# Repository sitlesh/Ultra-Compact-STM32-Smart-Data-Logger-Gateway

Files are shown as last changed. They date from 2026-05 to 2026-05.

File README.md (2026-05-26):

# Custom Embedded Controller Board with Micro SD Storage

A professionally designed, compact **2-layer printed circuit board (PCB)** developed using **KiCad 8.0**. This hardware platform is engineered for standalone embedded applications requiring localized data logging, high-precision timing, and robust power delivery.

---

## 📸 Hardware Showcase

### 🏷️ 3D Render Preview
Ultra-Compact STM32 Smart Data Logger Gateway

### 🗺️ Board Layout (Top & Bottom View)
| Top Copper Layer (F.Cu) | Bottom Copper Layer (B.Cu) |
| :---: | :---: |
| Screenshot (32) | Screenshot (33) |

---

## 🚀 Key Hardware Features

* **Micro SD Card Slot (J4):** Wired via high-speed SPI interface. Features localized decoupling, direct short-return paths to ground, and integrated mechanical shield grounding (`SH GND`) to suppress ESD and EMI.
* **Dual-Clock Architecture:** * **High-Speed Crystal (Y1 - 8MHz):** Provides a stable external clock source for the primary microcontroller core, stabilized by 20pF loading capacitors.
  * **Low-Speed RTC Crystal (Y2 - 32.768kHz):** Dedicated ultra-low-power crystal with 10pF loading capacitors for precise time-stamping.
* **Power Management:** Heavy-duty 2-position screw terminal (`J1`) for power input, protected by a robust on-board Schottky/Rectifier Diode (`D1`) for reverse polarity protection.
* **Signal Integrity:** Utilizes duplicated, stitched copper zones (`GND`) across both layers to maximize thermal dissipation, lower loop inductance, and suppress high-frequency noise.

---

## 📁 Repository Directory & File Descriptions

This repository contains all the native design assets and manufacturing files required to replicate or modify this project.

### 🛠️ Source Design Files (KiCad 8.0)
* **[`Ultra-Compact STM32 Smart Data Logger & Gateway.kicad_pro`](./Ultra-Compact%20STM32%20Smart%20Data%20Logger%20%26%20Gateway.kicad_pro)** : The master KiCad project file that links the schematic and PCB layout configurations together.
* **[`Ultra-Compact STM32 Smart Data Logger & Gateway.kicad_sch`](./Ultra-Compact%20STM32%20Smart%20Data%20Logger%20%26%20Gateway.kicad_sch)** : The complete schematic capture. Contains the logical circuit connections, component symbols, and electrical nets.
* **[`Ultra-Compact STM32 Smart Data Logger & Gateway.kicad_pcb`](./Ultra-Compact%20STM32%20Smart%20Data%20Logger%20%26%20Gateway.kicad_pcb)** : The physical 2-layer board layout, trace routing, component footprints, and copper ground planes.
* **[`gitignore.txt`](./gitignore.txt)** : Configured to exclude local KiCad auto-saves and temporary backup files to keep the repository clean.

### 📦 Manufacturing Files
* **[`Download Pre-packaged Gerbers ZIP (Gerbers.zip)`](./Gerbers.zip)** : Contains the combined ZIP archive. Click this link and hit the **Download** button on the next page to get all production-ready Gerber and Drill files for direct manufacturing.

---

## ⚙️ Fabrication Specifications

| Parameter | Specification |
| :--- | :--- |
| **Material Type** | FR-4 Standard |
| **Layer Count** | 2 Layers |
| **Board Thickness** | 1.6 mm |
| **Copper Weight** | 1 oz (35μm) outer layers |
| **Surface Finish** | HASL (with lead) or ENIG |
| **Solder Mask** | User Preference (Green/Blue/Black) |
| **Silkscreen** | White (High contrast) |

---

## 📝 License
This hardware design is open-source. Feel free to clone, modify, and build upon it for your own custom applications.

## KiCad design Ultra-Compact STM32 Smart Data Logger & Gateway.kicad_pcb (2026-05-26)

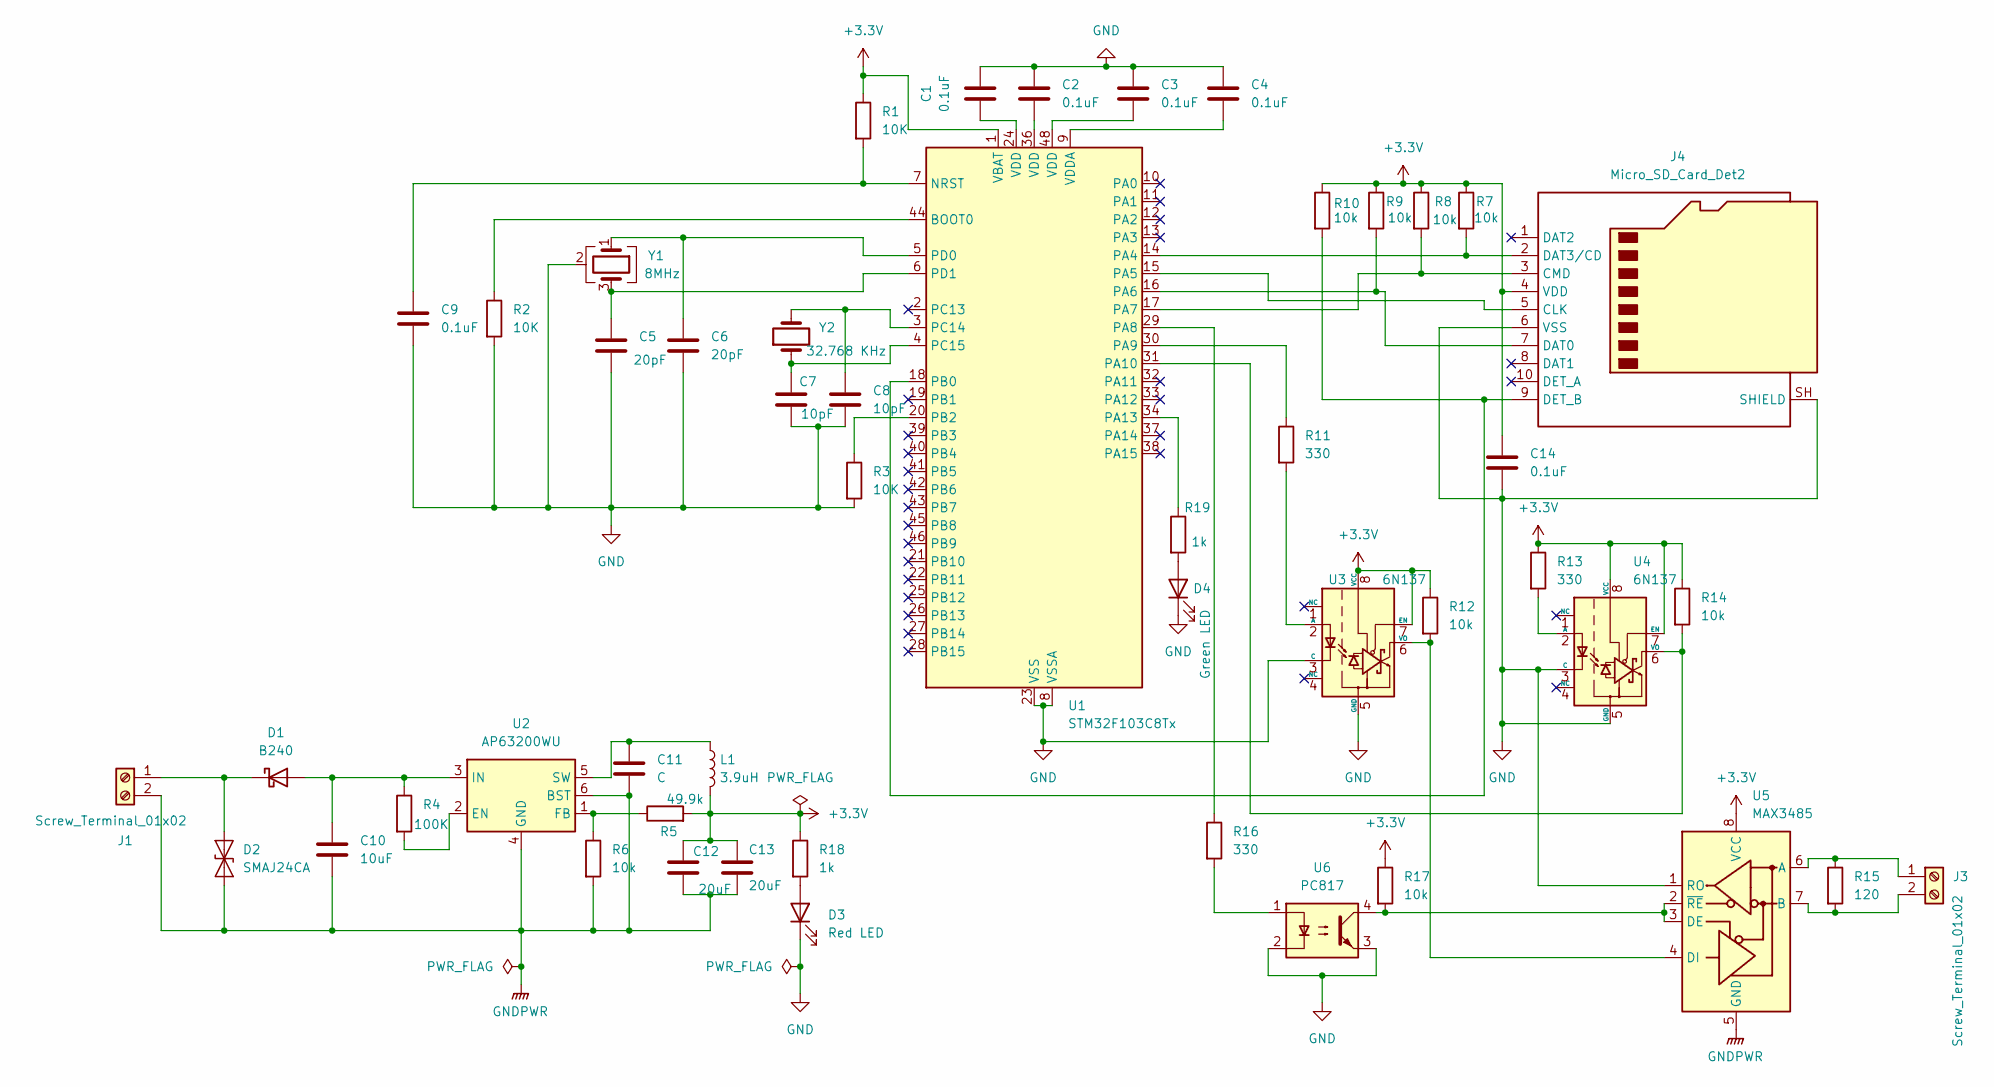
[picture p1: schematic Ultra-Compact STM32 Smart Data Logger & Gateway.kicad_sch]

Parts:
C1, C2, C3, C4, C9, C14: 0.1uF; C_0603_1608Metric
C5, C6: 20pF; C_0603_1608Metric
C7, C8: 10pF; C_0603_1608Metric
C10: 10uF; C_0603_1608Metric
C11: C; C_0603_1608Metric
C12, C13: 20uF; C_0603_1608Metric
D1: B240; D_SMB
D2: SMAJ24CA; D_SMA
D3: Red LED; LED_0805_2012Metric
D4: Green LED; LED_0805_2012Metric
J1, J3: Screw_Terminal_01x02; TerminalBlock_Phoenix_MKDS-1,5-2-5.08_1x02_P5.08mm_Horizont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
J4: Micro_SD_Card_Det2; microSD_HC_Molex_104031-0811
L1: 3.9uH; L_6.3x6.3_H3
R1, R2, R3: 10K; R_0805_2012Metric
R4: 100K; R_0805_2012Metric
R5: 49.9k; R_0805_2012Metric
R6, R7, R8, R9, R10, R12, R14, R17: 10k; R_0805_2012Metric
R11, R13, R16: 330; R_0805_2012Metric
R15: 120; R_0805_2012Metric
R18, R19: 1k; R_0805_2012Metric
U1: STM32F103C8Tx; LQFP-48_7x7mm_P0.5mm
U2: AP63200WU; TSOT-23-6
U3, U4: 6N137; SMDIP-8_W7.62mm
U5: MAX3485; SOIC-8_3.9x4.9mm_P1.27mm
U6: PC817; SMDIP-4_W7.62mm
Y1: 8MHz; Crystal_SMD_3225-4Pin_3.2x2.5mm
Y2: 32.768 KHz; Crystal_SMD_2012-2Pin_2.0x1.2mm

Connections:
+3.3V: C12.1, C13.1, C14.1, J4.4 (VDD), L1.2, R1.1, R5.2, R7.1, R8.1, R9.1, R10.1, R12.1, R13.1, R14.1, R17.1, R18.1, U1.1 (VBAT), U3.7 (EN), U3.8 (VCC), U4.7 (EN), U4.8 (VCC), U5.8 (VCC)
GND: C1.2, C2.2, C3.2, C4.2, C5.2, C6.2, C7.2, C8.2, C9.2, C14.2, D3.1 (K), D4.1 (K), J4.6 (VSS), J4.SH (SHIELD), R2.2, R3.2, U1.8 (VSSA), U1.23 (VSS), U1.35 (VSS), U1.47 (VSS), U3.3 (C), U3.5 (GND), U4.3 (C), U4.5 (GND), U5.1 (RO), U6.2, U6.3, Y1.2 (G), Y1.4 (G)
GNDPWR: C10.2, C11.2, C12.2, C13.2, D2.1 (A1), J1.2, R6.2, U2.4 (GND), U2.6 (BST), U5.5 (GND)
unnamed: C1.1, U1.24 (VDD)
unnamed: C2.1, U1.36 (VDD)
unnamed: C3.1, U1.48 (VDD)
unnamed: C10.1, D1.2 (A), R4.1, U2.3 (IN)
unnamed: D1.1 (K), D2.2 (A2), J1.1
unnamed: D3.2 (A), R18.2
unnamed: D4.2 (A), R19.2
unnamed: J3.1, R15.1, U5.6 (A)
unnamed: J3.2, R15.2, U5.7 (B)
unnamed: J4.5 (CLK), U1.15 (PA5)
unnamed: J4.3 (CMD), R8.2, U1.17 (PA7)
unnamed: J4.7 (DAT0), R9.2, U1.16 (PA6)
unnamed: J4.2 (DAT3/CD), R7.2, U1.14 (PA4)
unnamed: J4.9 (DET_B), R10.2, U1.18 (PB0)
unnamed: R16.2, U6.1
unnamed: R2.1, U1.44 (BOOT0)
unnamed: C9.1, R1.2, U1.7 (NRST)
unnamed: R16.1, U1.29 (PA8)
unnamed: R11.1, U1.30 (PA9)
unnamed: R14.2, U1.31 (PA10), U4.6 (VO)
unnamed: R19.1, U1.34 (PA13)
unnamed: R3.1, U1.20 (PB2)
unnamed: C8.1, U1.3 (PC14), Y2.2
unnamed: C7.1, U1.4 (PC15), Y2.1
unnamed: C6.1, U1.5 (PD0), Y1.1
unnamed: C5.1, U1.6 (PD1), Y1.3
unnamed: C4.1, U1.9 (VDDA)
unnamed: R4.2, U2.2 (EN)
unnamed: R5.1, R6.1, U2.1 (FB)
unnamed: C11.1, L1.1, U2.5 (SW)
unnamed: R11.2, U3.2 (A)
unnamed: R12.2, U3.6 (VO), U5.4 (DI)
unnamed: R13.2, U4.2 (A)
unnamed: R17.2, U5.2 (~RE), U5.3 (DE), U6.4

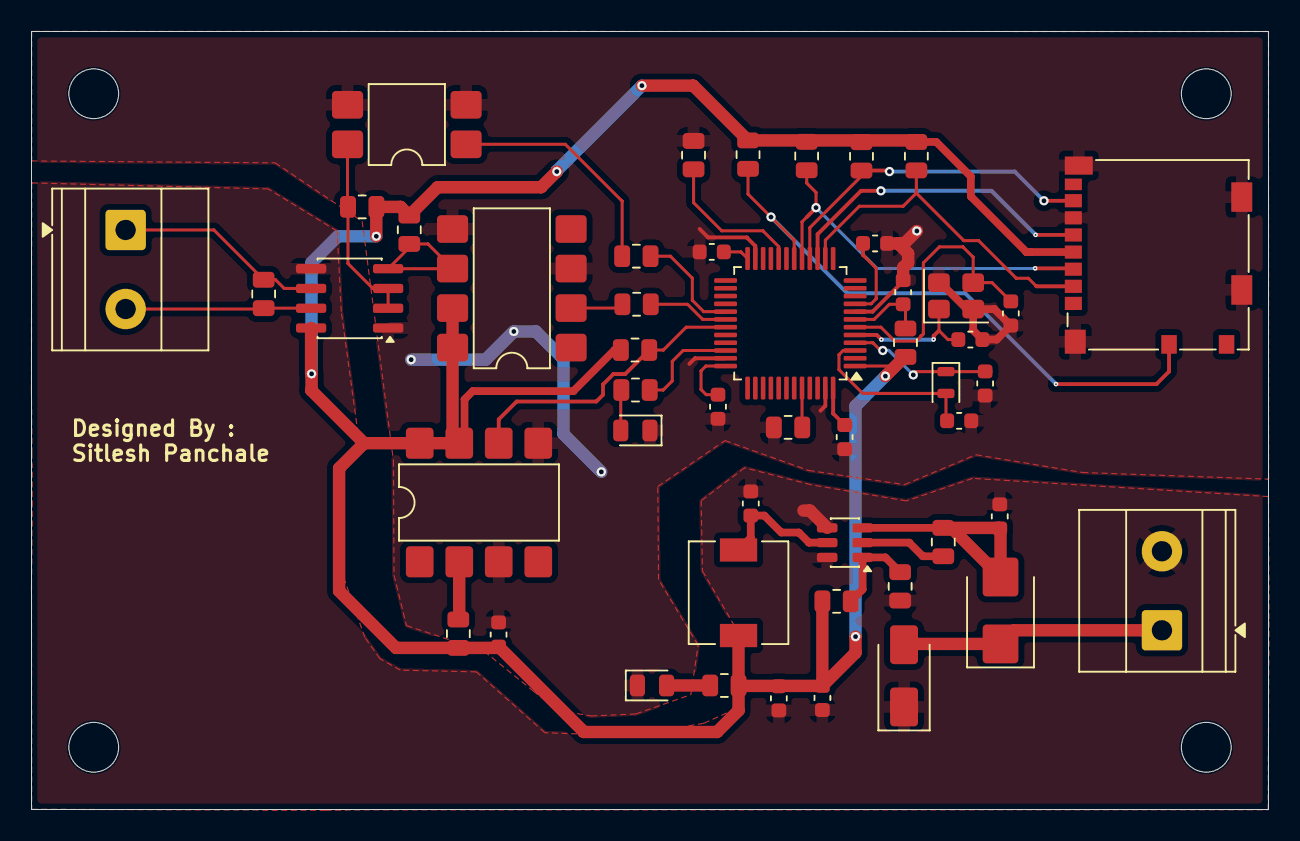
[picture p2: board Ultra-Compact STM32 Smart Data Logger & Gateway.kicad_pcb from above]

Board: 2 copper layers, 79.5 x 50.0 mm, 49 parts (0 on the bottom side), 37 nets.
